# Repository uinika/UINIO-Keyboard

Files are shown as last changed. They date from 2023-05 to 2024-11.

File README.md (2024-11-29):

# UINIO-Keyboard 多功能输入模组

[**UINIO-Keyboard**](https://gitee.com/uinika/UINIO-Keyboard) 是一款基于[**江苏沁恒 CH452**](https://www.wch.cn/products/CH452.html) 的 64 位键盘输入装置，采用两线制的 **I²C** 总线通信接口，并且外扩有[**日本阿尔卑斯阿尔派（ALPSALPINE）**](https://www.alpsalpine.com/) 的 3 枚 **EC11** 旋转编码器、以及 1 枚 **RKJXV** 模拟量碳膜摇杆，基本覆盖了嵌入式开发当中主流的实体输入方案。

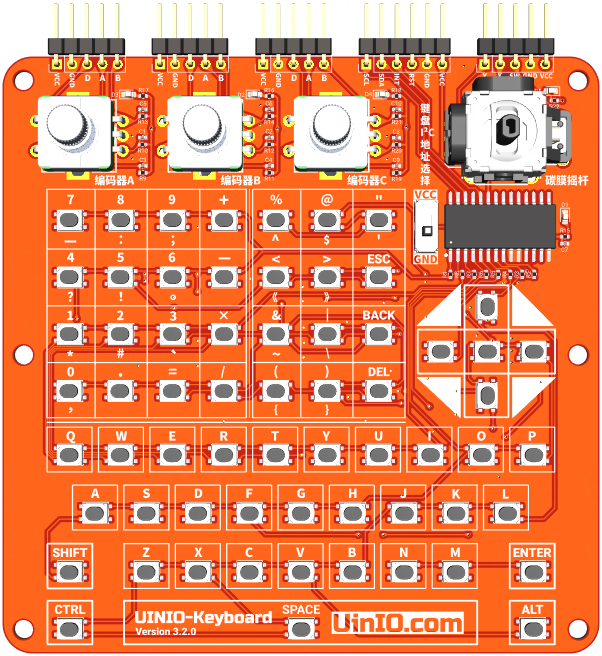
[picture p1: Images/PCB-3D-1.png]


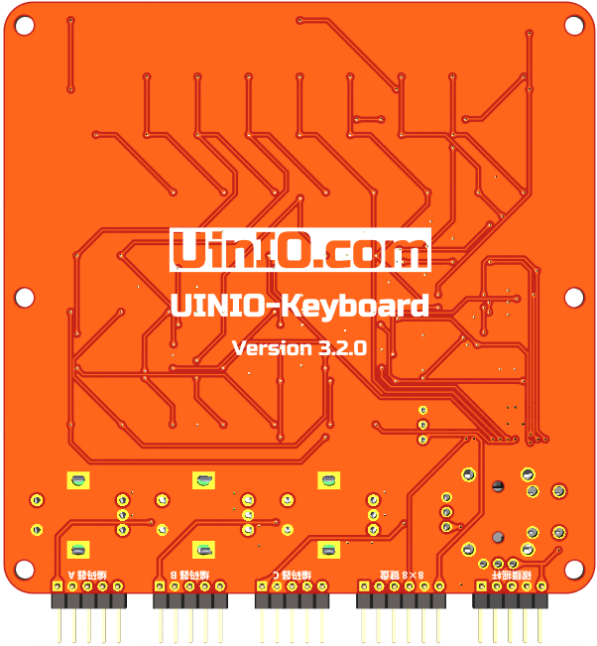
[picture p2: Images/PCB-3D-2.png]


## 设计概要

1. 同时板载有 **编码键盘**、**旋转编码器**、**模拟量摇杆** 三种常用的输入外设；
2. 添加了六枚 `3mm` 直径的机械孔，便于使用**铜柱**或者**螺丝**进行固定和安装；
3. 键盘按键使用 `3 × 4 × 2.5` 封装规格的四引脚贴片按键，这里可以购买日本[**阿尔卑斯阿尔派**](https://www.alpsalpine.com/c/)的 `SKRPACE010` 型，或者国产[**讯普精密**](https://www.xunpu.com.cn/)的 `TS-1089S-02526` 型微动按键；
4. 碳膜摇杆如果购买不到日本**阿尔卑斯阿尔派**（ALPS Alpine）的原厂型号，那么可以平替为国产的 [**广东控银 JP13**](http://www.k-silver.com/c_html_products/jp13heisedaikaiguan-825.html) 型摇杆；
5. 关于 64 位键盘的具体键位编码，以及参考驱动程序，可以查阅沁恒官方的[**《数码管驱动及键盘控制芯片 CH452 数据手册》**](https://www.wch.cn/downloads/CH452DS1_PDF.html)；

## 参考技术文档

[UinIO.com 电子技术实验室](http://uinio.com/) 为 **UINIO-Keyboard** 开源项目提供了如下参考技术资料：

- [《UINIO-Keyboard 核心板原理图》](http://uinio.com/my/works/UINIO-Keyboard/UINIO-Keyboard-Schematic.pdf)
- [《交互式 BOM 物料清单与 PCB 版图在线预览》](http://uinio.com/my/works/UINIO-Keyboard/UINIO-Keyboard-BOM.html)

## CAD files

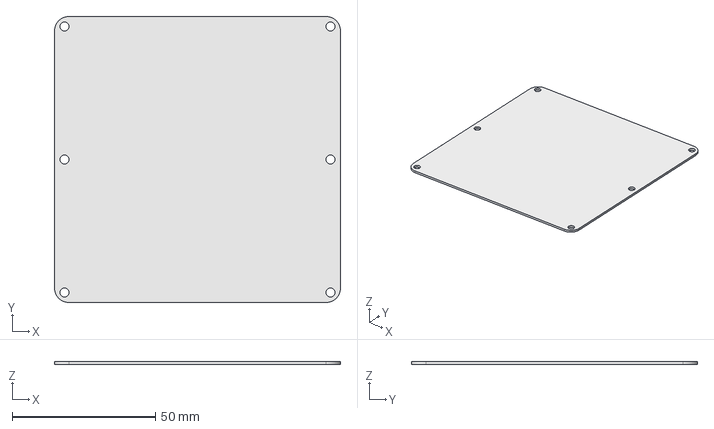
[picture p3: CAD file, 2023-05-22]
Edge/UINIO-Board-Edge.FCStd
100.0 x 100.0 x 1.00 mm

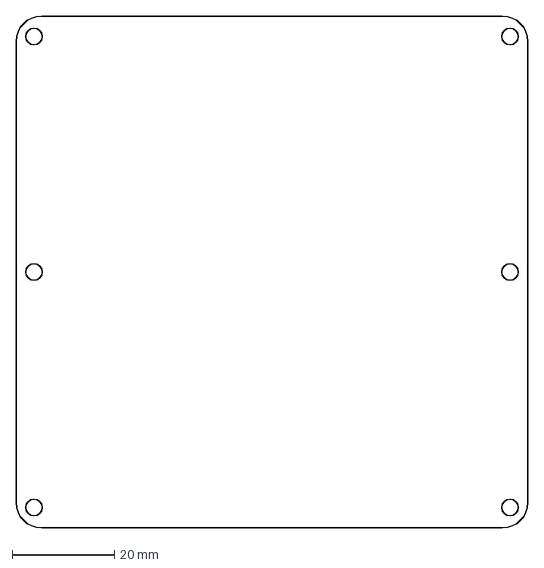
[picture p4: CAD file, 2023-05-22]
Edge/UINIO-Board-Edge-Body.dxf
100.0 x 100.0 mm

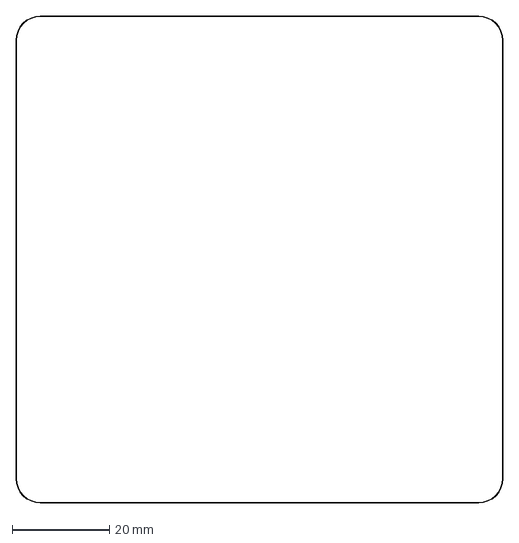
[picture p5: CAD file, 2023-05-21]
Edge/UINIO-Peg-Board-Edge-Body.dxf
100.0 x 100.0 mm

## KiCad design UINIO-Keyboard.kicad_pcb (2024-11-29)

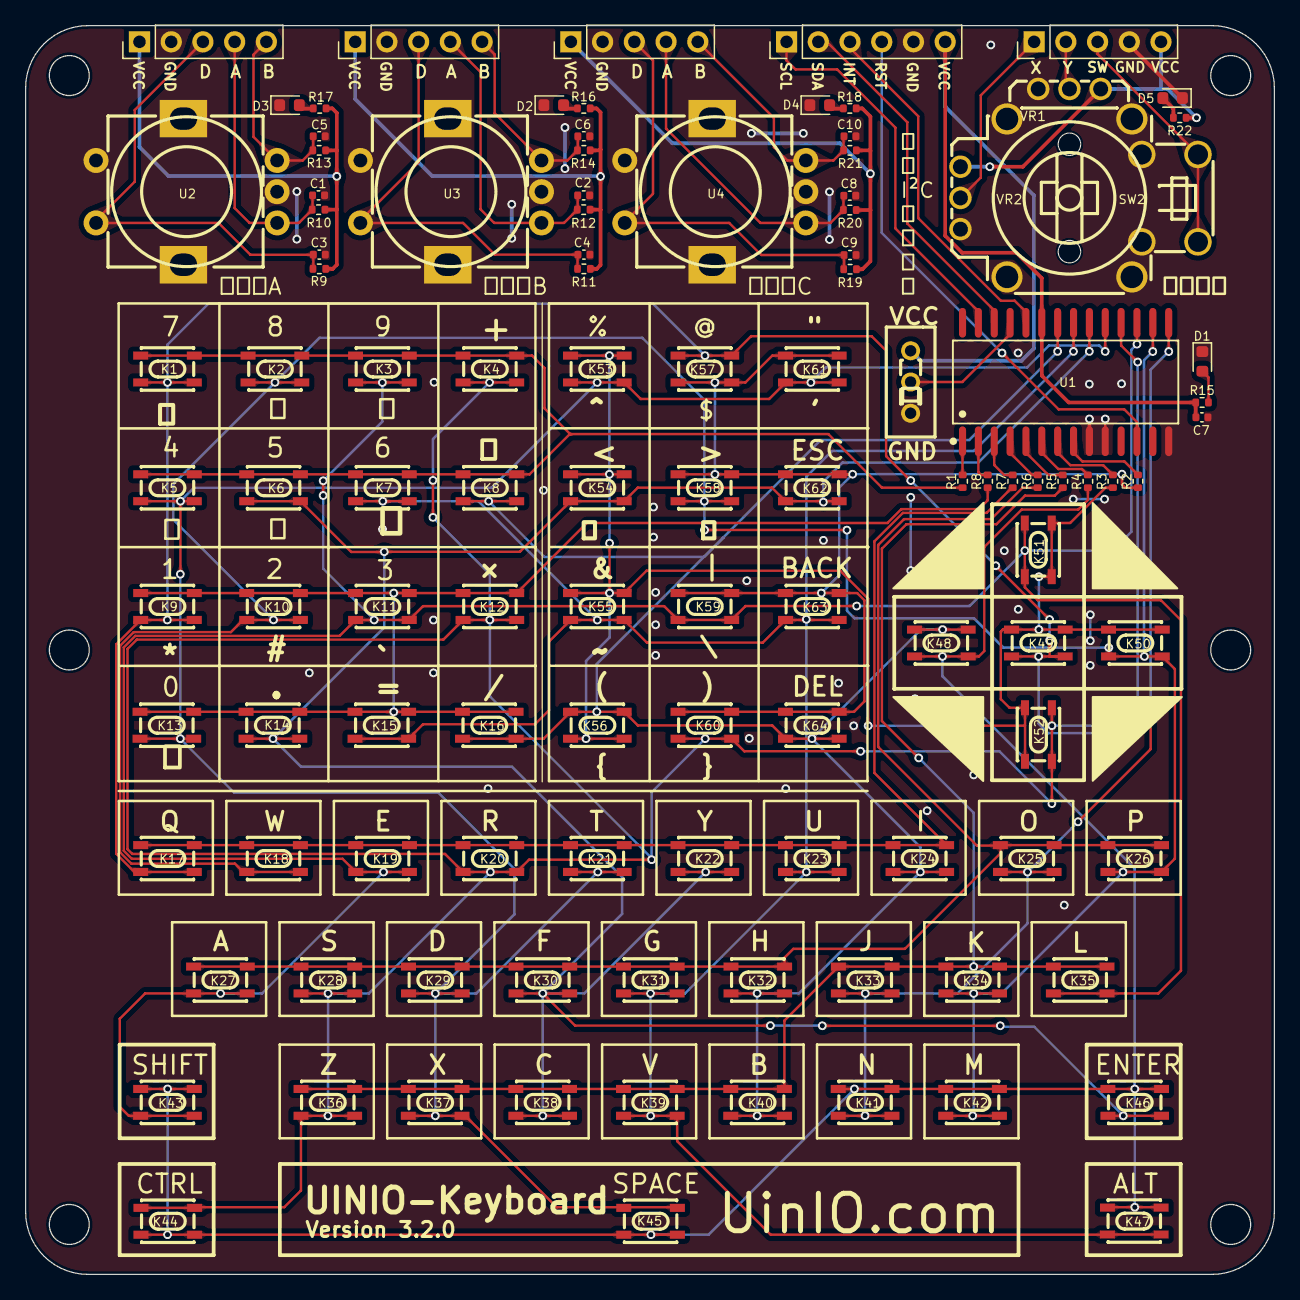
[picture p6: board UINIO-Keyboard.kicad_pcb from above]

Board: 2 copper layers, 100.0 x 100.0 mm, 112 parts (0 on the bottom side), 52 nets.

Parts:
C1, C2, C5, C6, C8, C10: 0.01uF; C_0402_1005Metric
C3, C4, C7, C9: 0.1uF; C_0402_1005Metric
D1, D2, D3, D4, D5: LED_Red; LED_0603_1608Metric
J1: Conn_01x06_Pin; PinHeader_1x06_P2.54mm_Vertical
J2, J3, J4, J5: Conn_01x05_Pin; PinHeader_1x05_P2.54mm_Vertical
K1, K2, K3, K4, K5, K6, K7, K8, K9, K10, K11, K12, K13, K14, K15, K16, K17, K18, K19, K20, K21, K22, K23, K24, K25, K26, K27, K28, K29, K30, K31, K32, K33, K34, K35, K36, K37, K38, K39, K40, K41, K42, K43, K44, K45, K46, K47, K48, K49, K50, K51, K52, K53, K54, K55, K56, K57, K58, K59, K60, K61, K62, K63, K64: A; KEY-SMD_4P-L4.2-W3.4-P2.15-LS4.7
R1, R2, R3, R4, R5, R6, R7, R8, R9, R10, R11, R12, R13, R14, R19, R20, R21: 10K; R_0402_1005Metric
R15, R16, R17, R18, R22: 2K; R_0402_1005Metric
SW1: SWITCH_SS12D00G3; SW-TH_SS-12D01-GX
SW2: RKJXV1224005; SW-TH_RKJXV1224005
U1: CH452A; SOIC-28_L17.9-W7.5-P1.27-LS10.3-BL
U2, U3, U4: EC1106S; SW-TH_EC11S

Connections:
/DCLK: J1.1, U1.27 (DCLK)
/DIG0: R1.1, U1.8 (DIG0)
/DIG1: R2.1, U1.7 (DIG1)
/DIG2: R3.1, U1.6 (DIG2)
/DIG3: R4.1, U1.5 (DIG3)
/DIG4: R5.1, U1.4 (DIG4)
/DIG5: R6.1, U1.3 (DIG5)
/DIG6: R7.1, U1.2 (DIG6)
/DIG7: R8.1, U1.1 (DIG7)
/DIN: J1.2, U1.26 (DIN)
/DOUT: J1.3, U1.24 (DOUT)
/EC11-A-1: C1.1, J2.4, R10.1, U2.1 (A)
/EC11-A-2: C2.1, J3.4, R12.1, U3.1 (A)
/EC11-A-3: C8.1, J5.4, R20.1, U4.1 (A)
/EC11-B-1: C5.1, J2.5, R13.1, U2.3 (B)
/EC11-B-2: C6.1, J3.5, R14.1, U3.3 (B)
/EC11-B-3: C10.1, J5.5, R21.1, U4.3 (B)
/EC11-D-1: C3.1, J2.3, R9.1, U2.5 (D)
/EC11-D-2: C4.1, J3.3, R11.1, U3.5 (D)
/EC11-D-3: C9.1, J5.3, R19.1, U4.5 (D)
/EC11-VCC-1: J2.1, R9.2, R10.2, R13.2, R17.2
/EC11-VCC-2: J3.1, R11.2, R12.2, R14.2, R16.2
/EC11-VCC-3: J5.1, R18.2, R19.2, R20.2, R21.2
/LOAD: SW1.2, U1.25 (LOAD)
/RST: J1.4, U1.12 (RST)
/Rocker_SW: J4.3, SW2.b, SW2.d
/Rocker_VCC: J4.5, R22.2, SW2.1 (B), SW2.4 (A)
/Rocker_X: J4.1, SW2.5 (DTA)
/Rocker_Y: J4.2, SW2.2 (DTA)
/SEG0: K1.3, K1.4, K9.3, K9.4, K17.3, K17.4, K25.3, K25.4, K33.3, K33.4, K41.3, K41.4, K49.3, K49.4, K57.3, K57.4, U1.15 (SEG0)
/SEG1: K2.3, K2.4, K10.3, K10.4, K18.3, K18.4, K26.3, K26.4, K34.3, K34.4, K42.3, K42.4, K50.3, K50.4, K58.3, K58.4, U1.16 (SEG1)
/SEG2: K3.3, K3.4, K11.3, K11.4, K19.3, K19.4, K27.3, K27.4, K35.3, K35.4, K43.3, K43.4, K51.3, K51.4, K59.3, K59.4, U1.17 (SEG2)
/SEG3: K4.3, K4.4, K12.3, K12.4, K20.3, K20.4, K28.3, K28.4, K36.3, K36.4, K44.3, K44.4, K52.3, K52.4, K60.3, K60.4, U1.18 (SEG3)
/SEG4: K5.3, K5.4, K13.3, K13.4, K21.3, K21.4, K29.3, K29.4, K37.3, K37.4, K45.3, K45.4, K53.3, K53.4, K61.3, K61.4, U1.19 (SEG4)
/SEG5: K6.3, K6.4, K14.3, K14.4, K22.3, K22.4, K30.3, K30.4, K38.3, K38.4, K46.3, K46.4, K54.3, K54.4, K62.3, K62.4, U1.20 (SEG5)
/SEG6: K7.3, K7.4, K15.3, K15.4, K23.3, K23.4, K31.3, K31.4, K39.3, K39.4, K47.3, K47.4, K55.3, K55.4, K63.3, K63.4, U1.21 (SEG6)
/SEG7: K8.3, K8.4, K16.3, K16.4, K24.3, K24.4, K32.3, K32.4, K40.3, K40.4, K48.3, K48.4, K56.3, K56.4, K64.3, K64.4, U1.22 (SEG7)
/VCC: C7.1, J1.6, R15.2, SW1.3, U1.23 (VCC)
GND: C1.2, C2.2, C3.2, C4.2, C5.2, C6.2, C7.2, C8.2, C9.2, C10.2, D1.1 (K), D2.1 (K), D3.1 (K), D4.1 (K), D5.1 (K), J1.5, J2.2, J3.2, J4.4, J5.2, SW1.1, SW2.3 (A), SW2.6 (B), SW2.7 (GND), SW2.8 (GND), SW2.9 (GND), SW2.10 (GND), SW2.a, SW2.c, U1.9 (GND), U1.10 (GND), U1.14 (H3L2), U2.2 (C), U2.4 (E), U2.6 (EP), U2.7 (EP), U3.2 (C), U3.4 (E), U3.6 (EP), U3.7 (EP), U4.2 (C), U4.4 (E), U4.6 (EP), U4.7 (EP)
unnamed: D1.2 (A), R15.1
unnamed: D2.2 (A), R16.1
unnamed: D3.2 (A), R17.1
unnamed: D4.2 (A), R18.1
unnamed: D5.2 (A), R22.1
unnamed: K1.1, K1.2, K2.1, K2.2, K3.1, K3.2, K4.1, K4.2, K5.1, K5.2, K6.1, K6.2, K7.1, K7.2, K8.1, K8.2, R8.2
unnamed: K9.1, K9.2, K10.1, K10.2, K11.1, K11.2, K12.1, K12.2, K13.1, K13.2, K14.1, K14.2, K15.1, K15.2, K16.1, K16.2, R7.2
unnamed: K17.1, K17.2, K18.1, K18.2, K19.1, K19.2, K20.1, K20.2, K21.1, K21.2, K22.1, K22.2, K23.1, K23.2, K24.1, K24.2, R6.2
unnamed: K25.1, K25.2, K26.1, K26.2, K27.1, K27.2, K28.1, K28.2, K29.1, K29.2, K30.1, K30.2, K31.1, K31.2, K32.1, K32.2, R5.2
unnamed: K33.1, K33.2, K34.1, K34.2, K35.1, K35.2, K36.1, K36.2, K37.1, K37.2, K38.1, K38.2, K39.1, K39.2, K40.1, K40.2, R4.2
unnamed: K41.1, K41.2, K42.1, K42.2, K43.1, K43.2, K44.1, K44.2, K45.1, K45.2, K46.1, K46.2, K47.1, K47.2, K48.1, K48.2, R3.2
unnamed: K49.1, K49.2, K50.1, K50.2, K51.1, K51.2, K52.1, K52.2, K53.1, K53.2, K54.1, K54.2, K55.1, K55.2, K56.1, K56.2, R2.2
unnamed: K57.1, K57.2, K58.1, K58.2, K59.1, K59.2, K60.1, K60.2, K61.1, K61.2, K62.1, K62.2, K63.1, K63.2, K64.1, K64.2, R1.2

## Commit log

2023-03-10 Initialize the project.
    [UINIO-Keyboard.kicad_pcb, UINIO-Keyboard.kicad_sch]
2023-03-13 Update PCB
2023-03-14 Update PCB.
2023-05-17 Complete schematic drawing.
    [UINIO-Keyboard.kicad_pcb, UINIO-Keyboard.kicad_sch]
2023-05-18 PCB Layout.
    [UINIO-Keyboard.kicad_pcb, UINIO-Keyboard.kicad_sch]
2023-05-20 Update PCB Layout.
    [UINIO-Keyboard.kicad_pcb, UINIO-Keyboard.kicad_sch]
2023-05-22 Complete PCB layout.
    [UINIO-Keyboard.kicad_pcb, UINIO-Keyboard.kicad_sch]
2023-05-24 Finish PCB layout.
    [UINIO-Keyboard.kicad_pcb, UINIO-Keyboard.kicad_sch]
2023-05-25 Release UINIO-Keyboard version 1.0.0.
    [UINIO-Keyboard-B_Cu.gbl, UINIO-Keyboard-B_Mask.gbs, UINIO-Keyboard-B_Paste.gbp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]
2023-05-29 Prepare version 2.0.0.
    [UINIO-Keyboard.kicad_sch]
2023-06-25 Release UINIO-Keyboard version 2.0.0.
    [UINIO-Keyboard-B_Cu.gbl, UINIO-Keyboard-B_Mask.gbs, UINIO-Keyboard-B_Paste.gbp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]
2023-06-27 Prepare 3.0.0.
    [UINIO-Keyboard.kicad_sch]
2023-06-27 Release UINIO-Keyboard version 3.0.0.
    [UINIO-Keyboard-B_Cu.gbl, UINIO-Keyboard-B_Mask.gbs, UINIO-Keyboard-B_Paste.gbp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]
2023-06-29 Release UINIO-Keyboard veresion 3.0.0.
    [UINIO-Keyboard-B_Cu.gbl, UINIO-Keyboard-B_Mask.gbs, UINIO-Keyboard-B_Paste.gbp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]
2023-07-09 Release UINIO-Keyboard version 3.1.0.
    [UINIO-Keyboard-B_Cu.gbl, UINIO-Keyboard-B_Mask.gbs, UINIO-Keyboard-B_Paste.gbp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]
2024-01-11 Release UINIO-Keyboard version 3.1.1.
    [UINIO-Keyboard-B_Cu.gbl, UINIO-Keyboard-B_Mask.gbs, UINIO-Keyboard-B_Paste.gbp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]
2024-11-29 Release UINIO-Keyboard version 3.2.0.
    [UINIO-Keyboard-B_Cu.gbl, UINIO-Keyboard-B_Mask.gbs, UINIO-Keyboard-B_Paste.gbp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]
